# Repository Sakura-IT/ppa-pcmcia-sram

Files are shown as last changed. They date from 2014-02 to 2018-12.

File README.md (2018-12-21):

ppa-pcmcia-sram
===============

PCMCIA SRAM card created on ppa.pl forum.

* board - electrical schematics and board layout (Eagle, Gerber)
* cpld/src - CPLD core source (VHDL)
* docs - documentation (manual)

For history and rationale behind design decisions, See this thread: http://www.ppa.pl/forum/amiga/29264/budowa-kart-pamieci-sram-na-pcmcia

This board was sold and marketed as Sakura 4MB PCMCIA SRAM, primarily by Sakura IT, though several forks of this design exist.

Description
===========

Add 4MB of Fast RAM to your unexpanded Amiga 600/1200. This additional memory will make your system much faster and allow to run more demanding games and applications. It was designed by Jarosław Bieliński and Radosław Kujawa.

This memory expansion card has the following features:

* Adds 4MB of Fast RAM to Amiga 600 or Amiga 1200.
* Built using modern, high performance 55ns SRAM ICs (even faster than maximum Amiga 1200 slot access time).
* Accelerates unexpanded Amiga 1200 to at least 1.67 MIPS (according to SysInfo).
* Fully PCMCIA 2.1 compliant on an electrical level, smaller dimensions than normal PCMCIA card.
* Very simple installation - just insert the card into PCMCIA slot on the left side of Amiga.
* Compatible with all PCMCIA friendly accelerators and memory expansions.
* Open source design. 
* RoHS compliant, low power, environmentally friendly.
* Made by Amigans for Amigans!

We did our best to ensure that this card works on as many configurations as possible, but some accelerator and Fast RAM expansion designs are inherently incompatible with PCMCIA slot if more than 4MB of memory is installed. Note that PCMCIA SRAM should work with them anyway, if less than 4MB Fast was installed on the turbo card. Of course, if you don’t have any accelerator, you don’t have to worry about that.

The following A1200 cards are known to be PCMCIA compatible and should work correctly with any amount of memory installed:

* Blizzard 1230/1240/1260.
* Apollo 1240/1260.
* ACA 1220/1230/1231/1232.
* most other turbo cards supporting more than 8MB of Fast memory.
* 4MB Fast trapdoor expansions without CPU.

The following A1200 cards are known to be problematic if more than 4MB of memory is installed:

* Apollo/Elbox/Viper 1230LC.
* M-Tec 1230/28.
* Blizzard 1220 if more than 4MB RAM installed.
* 8MB Fast trapdoor expansions without CPU.

The following A600 cards are known to be PCMCIA compatible and should work correctly:

* ACA630.
* 4MB Fast expansions attached on top of processor.

The following A600 cards are known to be problematic if more than 4MB of memory is installed:

* ACA620 (in default PCMCIA-incompatible mode).
* Ninetails (in default PCMCIA-incompatible mode).
* 8MB/9.5MB Fast expansions attached on top of processor.

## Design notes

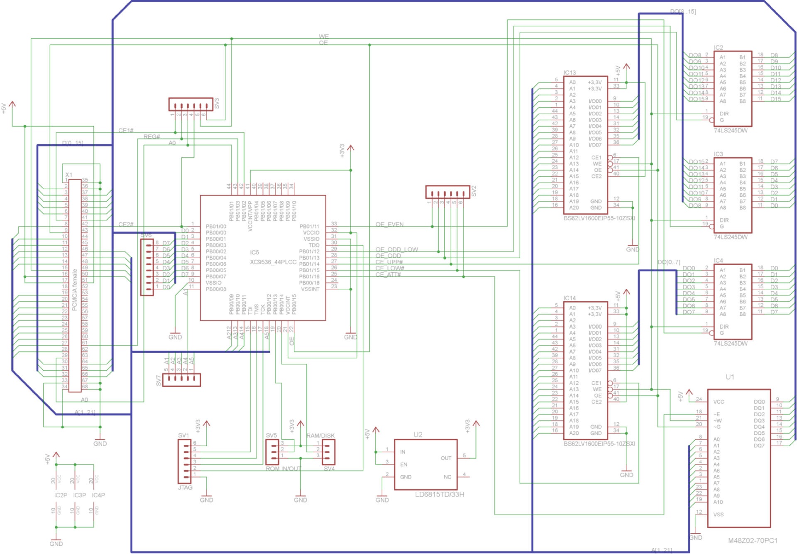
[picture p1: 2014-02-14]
board/Proto/schematics.jpg

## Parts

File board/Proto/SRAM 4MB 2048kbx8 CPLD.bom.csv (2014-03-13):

Part | Value | Device | Package | Description | MF | MPN | OC_FARNELL | OC_NEWARK | PACKAGE | SUPPLIER
C1 | 1uF/6,3V | CPOL-EUB | PANASONIC_B | POLARIZED CAPACITOR, European symbol
C2 | 1uF/6,3V | CPOL-EUB | PANASONIC_B | POLARIZED CAPACITOR, European symbol
C3 | 0,1uF | C-EUC0603 | C0603 | CAPACITOR, European symbol
C4 | 0,1uF | C-EUC0603 | C0603 | CAPACITOR, European symbol
C5 | 0,1uF | C-EUC0603 | C0603 | CAPACITOR, European symbol
C6 | 0,1uF | C-EUC0603 | C0603 | CAPACITOR, European symbol
C7 | 0,1uF | C-EUC0603 | C0603 | CAPACITOR, European symbol
C9 | 0,1uF | C-EUC0603 | C0603 | CAPACITOR, European symbol
C10 | 0,1uF | C-EUC0603 | C0603 | CAPACITOR, European symbol
C11 | 0,1uF | C-EUC0603 | C0603 | CAPACITOR, European symbol
C12 | 0,1uF | C-EUC0603 | C0603 | CAPACITOR, European symbol
C13 | 0,1uF | C-EUC0603 | C0603 | CAPACITOR, European symbol
IC1 | M48Z02-70PC1 | M48Z02-70PC1 | DIP254P1524X965-24 | 5 V, 16 Kbit (2 Kb x 8) ZEROPOWER® SRAM |  | M48Z02-70PC1 | 9755748 | 89K1473 | PDIP-24 | STMICROELECTRONICS
IC2 | 74LS245DW | 74LS245DW | SO20W | Octal BUS TRANSCEIVER, 3-state
IC3 | 74LS245DW | 74LS245DW | SO20W | Octal BUS TRANSCEIVER, 3-state
IC4 | 74LS245DW | 74LS245DW | SO20W | Octal BUS TRANSCEIVER, 3-state
IC5 | XC9536_44PLCC | XC9536_44PLCC | PLCC44 | xc9536_pc44 XC9500 In-System Programmable CPLD Family |  | XC9536-15PCG44C | 1193226 | 98K3376
IC6 | BS62LV1600EIP55-10ZSXI | BS62LV1600EIP55-10ZSXI | TSOPII-Z44 | Source: CYPRESS cy7c1059dv33_8.pdf
IC7 | BS62LV1600EIP55-10ZSXI | BS62LV1600EIP55-10ZSXI | TSOPII-Z44 | Source: CYPRESS cy7c1059dv33_8.pdf
IC8 | LD6815TD/33H | LD6815TD/33H | SOT95P275X110-5N | LDO, 5.5V, 0.25VDO, 0.15A, 3.3V, 5TSOP |  | LD6815TD/33H | 2308302 | 69W9575 | TSOP-5 | NXP
SV1 | JTAG | MA06-1 | MA06-1 | PIN HEADER |  |  | unknown | unknown
SV2 |  | MA06-1 | MA06-1 | PIN HEADER |  |  | unknown | unknown
SV3 |  | MA06-1 | MA06-1 | PIN HEADER |  |  | unknown | unknown
SV4 | RAM/DISK | MA03-1 | MA03-1 | PIN HEADER |  |  | unknown | unknown
SV5 | ROM IN/OUT | MA03-1 | MA03-1 | PIN HEADER |  |  | unknown | unknown
SV6 |  | MA08-1 | MA08-1 | PIN HEADER |  |  | unknown | unknown
SV7 |  | MA05-1 | MA05-1 | PIN HEADER |  |  | unknown | unknown
X1 | PCMCIA female | 9M681X03TB9M681Z04 | 9M681X04

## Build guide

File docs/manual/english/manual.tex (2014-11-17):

\documentclass[10pt,a4paper]{article}
\usepackage{graphicx}
\usepackage{hyperref}
\usepackage[utf8x]{inputenc}

\begin{document}

\begin{titlepage}
\begin{center}

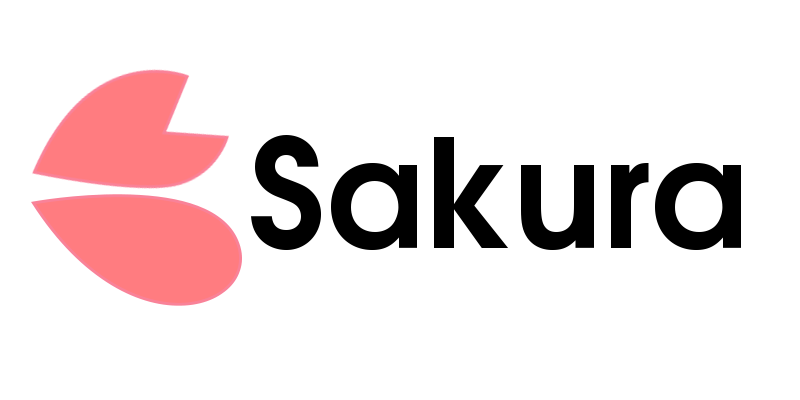
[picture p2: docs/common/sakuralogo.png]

\vfill

\huge
4MB PCMCIA SRAM

User's Manual

\vspace*{1cm}

\normalsize
Low cost Fast RAM expansion for Amiga 600/1200.

\vspace*{5cm}

\today

\end{center}
\end{titlepage}

\section*{Overview}

Thank you for purchasing Sakura 4MB PCMCIA SRAM expansion! This product has the following features:

\begin{itemize}
	\item Adds 4MB of Fast RAM to Amiga 600 or Amiga 1200.
	\item Accelerates unexpanded Amiga 1200 to at least 1.67 MIPS (according to SysInfo).
	\item Built using modern, high performance 55ns SRAM ICs.
	\item Very simple installation - just insert the card into PCMCIA slot on the left side of Amiga.
	\item Compatible with all PCMCIA friendly accelerators and memory expansions\footnote{We did our best to ensure that this card works on as many configurations as possible, but some accelerator and Fast RAM expansion designs are inherently incompatible with PCMCIA slot if more than 4MB of memory is installed. Note that PCMCIA SRAM should work with them anyway, if less than 4MB Fast was installed on the turbo card. Of course, if you don’t have any accelerator, you don’t have to worry about that.}.
	\item Open source design\footnote{Visit the source code reposity: \url{https://github.com/rkujawa/ppa-pcmcia-sram} .} under CC-BY-SA (board) and MIT (CPLD core) licenses.
	\item Made by Amigans for Amigans! 
\end{itemize}

\section*{Installation}

The installation process is very easy. To install the expansion perform the following steps:

\begin{itemize}
	\item Power down your Amiga.
	\item Slide the expansion card into PCMCIA slot, located on the left side of your computer. The card's components should be facing upwards.
	\item Be sure the {\tt RAM/disk} switch is in {\tt RAM} position.
	\item Turn on your Amiga and enjoy additional 4MB of memory.
\end{itemize}

Your Amiga should start as normal, albeit a bit faster. After installation you can confirm that the board is working correctly, by checking amount of available memory on the Workbench top menu bar, or with the {\tt avail} or {\tt ShowConfig} commands. Popular SysInfo tool will report the additional 4MB of memory under {\tt card.resource} name.

\section*{Technical details}

\begin{center}

\end{center}

Revision 2.x Sakura boards are built around Alliance Memory AS6C3216, which is a 55ns 32 megabit SRAM chip with 16-bit data bus. The memory is accessible within high 4MB of Zorro 2 memory ({\tt 0x600000-0x9FFFFF}) range.

Control signals for SRAM are generated by Xilinx XC9536XL CPLD, based on PCMCIA slot access signals.

This expansion is a completely autoconfiguring device. Memory is automatically added to the system memory pool by Kickstart. Autoconfiguration process is done according to the Card Information Structure (CIS) provided by the card, which is parsed by {\tt card.resource}. Naturally, this process only takes place during system startup, so inserting card into Amiga when it is running does not cause memory to be added. If necessary it could be added manually with {\tt AddMem} command (avaialble on aminet), although this is not required during normal operation.

Sakura expansion CIS contains optimal settings that allow best possible PCMCIA slot peformance:
\begin{itemize}
	\item On Amiga 600 Gayle chip is configured for 570ns access time by default, which results in performance similar to Fast RAM expansions attached on top of 68000 CPU.
	\item On Amiga 1200 the default configuration is 250ns access time, but Kickstart automatically reconfigures Gayle for 100ns access, according to CIS. This results in some performance increase compared to an unexpanded Amiga 1200. Contrary to popular opinions, Amiga 1200 equipped with high performance, correctly configured PCMCIA SRAM expansion (like this one) is performing better than Chip RAM only system.
\end{itemize}

CIS ROM is also implemented within XC9536XL CPLD.

Sakura expansion is electrically compatible with PCMCIA 2.1 standard, however physical dimensions of the card are smaller. While in theory this card should work with other devices, using it with computers other than Amiga 600/1200 was never tested and is discouraged.

\section*{Temporary disk mode}

It is possible to use the Sakura board as temporary virtual disk. To switch the board into this mode, take the following steps:
\begin{itemize}
	\item Turn off your Amiga and remove the Sakura board.
	\item Set the {\tt RAM/disk} switch into {\tt disk} position.
	\item Turn on your Amiga, instert the Sakura after booting into Workbench.
	\item Run the {\tt PrepCard} application.
	\item Select {\tt Prepare as disk} option.
	\item After your card is successfully prepared, reboot the Amiga.
	\item Notice the new volume named {\tt Empty} on your Workbench screen. Enjoy your temporary 4MB storage.

Card in this mode is handled by the device {\tt CC0}, which is provided by the Kickstart.
\end{itemize}

\section*{Troubleshooting}

\begin{itemize}
	\item Q: After powering up the Amiga, the memory does not appear on the Workbench bar and the output of {\tt ShowConfig} command.
	\item A: Check if the card is properly inserted into PCMCIA slot. Check if the {\tt RAM/Disk} switch is in the {\tt RAM} position. Reboot the Amiga.
\end{itemize}

\begin{itemize}
	\item Q: The memory is not automatically added to the system if Sakura card is inserted when Amiga is already powered on. 
	\item A: The probe procedure for PCMCIA memory is executed only during system startup. Reboot the Amiga to see the additional memory. 
\end{itemize}

\begin{itemize}
	\item Q: {\tt PrepCard} utility refuses to start, stating that memory is already configured. 
	\item A: It is not necessary to use {\tt PrepCard} with Sakura board configured as RAM. Predefined CIS settings are selected with {\tt RAM/Disk} switch. It is possible to view the current CIS settings by starting the {\tt PrepCard} just after inserting the card into Amiga (i.e. before reboot). 
\end{itemize}

\begin{itemize}
	\item Q: Performance of my Amiga 1200 dropped after installing the card.
	\item A: Be sure that {\tt RAM/disk} switch is in {\tt RAM} position. If not then turn off your Amiga completely, wait a few seconds and set the switch in {\tt RAM} position. After power-on you should notice considerable speedup.
\end{itemize}

\section*{Acknowledgements}

Sakura expansion was designed by Radosław ,,strim'' Kujawa and Jarosław ,,jarob'' Bieliński. The original idea was suggested on PPA.pl forum by RomanWorkshop. 

All schematics and board layout files are licensed under Creative Commons Attribution-ShareAlike 4.0 license. CPLD core source is licensed under MIT license.

The card is made in Poland and conforms to RoHS standard. 

All new cards sold through our exclusive dealer, RetroAmi, are covered by 24 months warranty. Due to open source nature of the project, note that {\bf only} cards produced by us (and therefore sold through RetroAmi) are covered by this warranty. In case of necessary service repairs please contact the shop directly. Do not attempt to repair the card yourself, it will void the warranty. Do not remove the sticker on the back of the card - it contains serial number. Please save the invoice/bill as a proof of transaction.

Thanks to everyone who preordered the board - you made this project happen!

\section*{Contact}

In case of any questions/inquires please contact RetroAmi:

\url{http://retroami.com.pl/} 

\end{document}

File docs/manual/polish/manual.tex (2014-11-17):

\documentclass[10pt,a4paper]{article}
\usepackage{graphicx}
\usepackage{hyperref}
\usepackage[utf8x]{inputenc}
\usepackage{polski}

\begin{document}

\begin{titlepage}
\begin{center}


\vfill

\huge
4MB PCMCIA SRAM

Instrukcja Obsługi

\vspace*{1cm}

\normalsize
Tanie rozszerzenie Fast RAM dla Amigi 600/1200.

\vspace*{5cm}

\today

\end{center}
\end{titlepage}

\section*{Opis}

Dziękujemy za zakup rozszerzenia Sakura 4MB PCMCIA SRAM! Ten produkt ma następujące właściwości:

\begin{itemize}
	\item Rozszerza Amigę 600 lub 1200 o 4MB pamięci Fast RAM.
	\item Przyśpiesza nierozszerzoną Amigę 1200 do przynajmniej 1.67 MIPS (według SysInfo).
	\item Jest zbudowany z użyciem nowoczesnych, szybkich układów SRAM o czasie dostępu 55ns.
	\item Bardzo prosta instalacja - zwyczajnie włóż kartę w slot PCMCIA po lewej stronie Amigi.
	\item Kompatybilny z wszystkimi akceleratorami oraz rozszerzeniami pamięci przyjaznymi dla slotu PCMCIA\footnote{Zrobiliśmy wiele aby zapewnić działanie karty w największej możliwej ilości konfiguracji, ale niektóre akceleratory oraz rozszerzenia Fast RAM są z założenia niekompatybilne ze slotem PCMCIA jeśli zainstalowane jest więcej niż 4MB pamięci. Karta PCMCIA SRAM powinna działać z nimi tak czy inaczej, jeśli na owym rozszerzeniu zainstalowane jest 4MB pamięci lub mniej. Oczywiście, jeśli nie masz żadnego akceleratora ani rozszerzenia pamięci, to nie musisz się tym przejmować.}.
	\item Otwarty projekt\footnote{Odwiedź repozytorium kodu źródłowego: \url{https://github.com/rkujawa/ppa-pcmcia-sram} .} na licencji CC-BY-SA (płytka) oraz MIT (wsad CPLD).
	\item Stworzony przez Amigowców dla Amigowców! 
\end{itemize}

%To reduce the price, card is delivered without any kind of case. The case might be available in the future from 3rd party vendor.

\section*{Instalacja}

Procedura instalacji jest bardzo prosta. Aby zainstalować rozszerzenie wykonaj następujące kroki:

\begin{itemize}
	\item Wyłącz swoją Amigę.
	\item Wsuń kartę do slotu PCMCIA, zlokalizowanego po lewej stronie Twojego komputera. 
	%The card's components should be facing upwards.
	\item Upewnij się że przełącznik {\tt RAM/disk} jest ustawiony w pozycji {\tt RAM}.
	\item Włącz swoją Amigę i rozkoszuj się dodatkowymi 4MB pamięci.
\end{itemize}

Twoja Amiga powinna uruchomić się jak zazwyczaj, jednak nieco szybciej. Po instalacji możesz potwierdzić, że rozszerzenie działa prawidłowo, poprzez sprawdzenie ilości dostępnej pamięci na górnej belce Workbench'a, albo używając komendy {\tt avail} lub {\tt ShowConfig}. Popularne narzędzie SysInfo zaraportuje dodatkowe 4MB pamięci pod nazwą {\tt card.resource}.

\section*{Szczegóły techniczne}

\begin{center}

\end{center}

Karty Sakura w rewizji 2.x są zbudowane w oparciu o układ Alliance Memory AS6C3216, który jest 32-megabitowym układem SRAM z 16-bitową szyną danych, o czasie dostępu 55ns. Pamięć jest dostępna w górnych 4MB przestrzeni Zorro 2 ({\tt 0x600000-0x9FFFFF}).

Sygnały kontrolne dla układu SRAM są generowane przez CPLD Xilinx XC9536XL, bazując na sygnałach dostępu do slotu PCMCIA.

To rozszerzenie jest konfigurowane w pełni automatycznie. Pamięć jest dodawana do systemowej puli pamięci przez Kickstart. Proces automatycznej konfiguracji jest wykonywany zgodnie z danymi przedstawianymi przez kartę w strukturze CIS (ang. Card Information Structure), które jest analizowana przez {\tt card.resource}. Naturalnie, ten proces ma miejsce jedynie podczas startu systemu, więc włożenie karty do Amigi podczas jej pracy nie powoduje automatycznego dodania pamięci. Jeśli jest to konieczne, istnieje możliwość ręcznego dodania pamięci za pomocą komendy {\tt AddMem} (dostępnej na aminecie), jednakże to nie jest wymagane podczas normalnej pracy. 

CIS rozszerzenia Sakura zawiera optymalne ustawienia, ktore pozwalają na uzyskanie optymalnej wydajności slotu PCMCIA:
\begin{itemize}
	\item W przypadku Amigi 600 układ Gayle jest konfigurowany domyślnie do pracy z czasem dostępu 570ns, co pozwala na osiągnięci wydajności podobnej do rozszerzeń Fast RAM zakładanych na procesor 68000.
	\item W przypadku Amigi 1200 domyślną konfiguracją jest czas dostępu 250ns, ale Kickstart automatycznie rekonfiguruje Gayle na dostęp z czasem 100ns, zgodnie z informacją w CIS. To skutkuje pewnym zwiększeniem wydajności w porównaniu do nierozszerzonej Amigi 1200. Przeciwnie do popularnych opinii, Amiga 1200 wyposażona w wydajne, poprawnie skonfigurowane rozszerzenie PCMCIA SRAM (takie jak Sakura) będzie oferowała wydajność większą niż system wyposażony jedynie w Chip RAM.
\end{itemize}

ROM zawierający CIS jest także zaimplementowany w CPLD XC9536XL.

Rozszerzenie Sakura jest elektrycznie kompatybilne ze standardem PCMCIA 2.1, jednakże fizyczne wymiary karty są mniejsze. W teorii to rozszerzenie powinno działać z innymi urządzeniami, jednak użycie z innymi komputerami niż Amiga 600/1200 nigdy nie zostało przetestowane i z tego względu nie jest zalecane.

\section*{Tryb tymczasowego dysku}

Jest możliwe wykorzystanie karty Sakura jako tymczasowego dysku. Aby przełączyć kartę w ten tryb, wykonaj następujące czynności:
\begin{itemize}
	\item Wyłącz swoją Amigę i wyjmij kartę Sakura.
	\item Ustaw przełącznik {\tt RAM/disk} w pozycji {\tt disk}.
	\item Włącz swoją Amigę, włóż kartę Sakura po uruchomieniu do Workbencha.
	\item Uruchom program {\tt PrepCard}.
	\item Skorzystaj z opcji {\tt Prepare as disk}.
	\item Gdy karta zostanie przygotowana, zrestartuj Amigę.
	\item Zauważ nowy wolumin {\tt Empty} na blacie Workbencha. Rozkoszuj się tymczasowym dyskiem 4MB.

Karta w tym trybie jest obsługiwana przez urządzenie {\tt CC0}, które dostarczone jest przez Kickstart.
\end{itemize}

\section*{Rozwiązywanie problemów}

\begin{itemize}
	\item P: Po włączeniu Amigi, pamięć nie pojawia się na belce Workbencha ani w wyniku polecenia {\tt ShowConfig}.
	\item O: Sprawdź czy karta jest prawidłowo umieszczona w slocie. Sprawdź czy przełącznik {\tt RAM/Disk} znajduje się w pozycji {\tt RAM}. Zrestartuj Amigę.
\end{itemize}

\begin{itemize}
	\item P: Pamięć nie jest automatycznie dodana do systemu w momencie włożenia karty, gdy Amiga jest już włączona.
	\item O: Procedura sprawdzająca czy pamięć PCMCIA jest obecna, wykonywana jest jedynie podczas startu systemu. Zrestartuj Amigę aby zobaczyć dodatkową pamięć. 
\end{itemize}

\begin{itemize}
	\item P: Program {\tt PrepCard} odmawia uruchomoenia, twierdząc że pamięć jest już skonfigurowana.
	\item O: Nie ma potrzeby używania programu {\tt PrepCard} z kartą Sakura skonfigurowaną jako RAM. Predefiniowane ustawienia CIS są wybierane przełącznikiem {\tt RAM/Disk}. Jest możliwe obejrzenie tych ustawień poprzez uruchomienie {\tt PrepCard} bezpośrednio po włożeniu karty do slotu (przed restartem). 
\end{itemize}

\begin{itemize}
	\item P: Wydajność mojej Amigi 1200 spadła po zainstalowaniu karty.
	\item O: Upewnij się, że przełącznik {\tt RAM/disk} znajduje się w pozycji {\tt RAM}. Jeśli nie to wyłącz całkowicie Amige, poczekaj kilka sekund, ustaw przełącznik w pozycji {\tt RAM}. Po uruchomieniu zauważysz znaczne przyśpieszenie.
\end{itemize}

\section*{Zastrzeżenia i podziękowania}

Rozszerzenie Sakura zostało opracowane przez Radosława ,,strim'' Kujawa oraz Jarosława ,,jarob'' Bielińskiego. Oryginalny pomysł został podsunięty na forum PPA.pl przez użytkownika RomanWorkshop. 

Wszystkie schematy i układ płytki są dostępne na licencji Creative Commons Attribution-ShareAlike 4.0. Wsad do układu CPLD został udostępniony na licencji MIT.

Karta została wyprodukowana w Polsce i jest zgodna ze standardem RoHS. 

Wszystkie nowe karty sprzedawane przez naszego wyłącznego sprzedawcę -- RetroAmi -- są objęte 24 miesięczną  gwarancją. Z uwagi na otwartą naturę tego projektu, zwróć uwagę że {\bf tylko} karty wyprodukowane przez nas (a więc sprzedawane przez RetroAmi) są objęte tą gwarancją. W przypadku wymaganych napraw gwarancyjnych prosimy o kontaktowanie się bezpośrednio ze sprzedawcą. Nie próbuj naprawiać karty samemu, spowoduje to utratę gwrancji. Nie usuwaj naklejki z karty - zawiera ona numer seryjny. Proszę zachować rachunek/fakturę jako dowód zakupu.

Dziękujemy wszystkim, którzy zamówili tą kartę - to wy sprawiliście, że ten projekt się udał!

\section*{Kontakt}

W przypadku jakichkolwiek pytań prosimy o kontakt z RetroAmi:

\url{http://retroami.com.pl/} 

\end{document}

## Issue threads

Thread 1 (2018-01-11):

Non-attribute memory SRAM cards

toastedcrumpets, 2018-01-11:
Hi!
Thanks for this amazing project. I'm currently looking for SRAM cards for old test equipment (in particular LeCroy 9300 series scopes). They require non-attribute memory PCMCIA SRAM cards, do you have any advice on how the CPLD VHDL might need to be modified to remove the CIS/attribute memory?
Kind regards,
Marcus

rkujawa, 2018-01-11:
Hi.

That should be relatively straightforward. Minimal modification removing attribute memory, would require changing `ce_attr_internal` to always be in an inactive state (1, since it's active low).

I.e. change lines 107-109 of main.vhd to:
```
ce_attr_internal <= '1';
```

This will essentially disable decoding of attribute ROM.

toastedcrumpets, 2018-01-11:
Thanks that's really simple. Do you still sell these via http://retroami.com.pl/? There's a number of people who might be interested in buying them over at the LeCroy users group if they work, but I'd like to test one first if I can.

rkujawa, 2018-01-12:
The cards are out of stock and for the time being, I am not planning a new production run (due to personal issues). So most likely you will need to make your own card. I am aware of quite a few people who have already done homebrew production of these cards.

Please note that the cards were not tested in anything but Amiga computers. They are also physically shorter than normal PCMCIA cards, so depending on the slot in your LeCroy scope, it might be necessary to adjust the PCB design. Also see issue #2.

toastedcrumpets, 2018-01-12:
Ah no problem, I hope your personal issues are swiftly resolved and thank you again for putting this together. I've seen that the Xilinx part for the v2.1 are out of production, but the v2.2 uses a BGA part which I've never soldered before, so I might try a 2mb card from ebay first before I try building my own!

rkujawa, 2018-01-13:
@toastedcrumpets You can use XC9536XL-10VQG44C in v2.1, this is still in production.

toastedcrumpets, 2018-01-19:
Thanks, I've ordered an SRAM from Ebay for now, but I don't doubt we might start making these if more scopes come in!

Kobbe1, 2024-05-05:
@toastedcrumpets sorry for resurrecting this but I am looking for an PCMCIA card for an old LeCroy scope too as it seems to have lost it's firmware, bit difficult to get my hands on one these days, so was wondering if you ever got this PCB built?

toastedcrumpets, 2024-05-05:
Hey, sorry no I didn't try it as I only needed the one card. If there's demand and no alternative source I could do a manufacturing run of these if needed with the vhdl changed, but I'm not planning this myself at the current time

Closed 2018-01-12.

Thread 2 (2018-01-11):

Board version 2.2 does not work reliably with ISSI PSRAM.

rkujawa, 2018-01-11:
Numerous tests have shown that ISSI PSRAM (as specified in board revision 2.2 BOM) does not work reliably. If one wants to build a card based on 2.2 PCB, then AS6C3216-55BIN should be used.

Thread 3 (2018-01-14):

PCMCIA connector EOL

rhaamo, 2018-01-14:
Hi,

On 2.2 PCB, I see that the PCMCIA connector is an ```FCI-10014744-002SLF```  and is out of stock/obsolete in Farnell and Mouser and pretty much everywhere, do you known a replacement for it ?

rkujawa, 2018-01-14:
Unfortunately, I am not aware of any direct replacement (I wasn't even aware that it is EOL now).

rhaamo, 2018-01-14:
Looks like Digikey still have PCMCIA connectors in stock.

It looks like http://www.plccenter.co.uk/Buy/ARROW/10014744002SLF?redirect=true may have this connector from ARROW and FIRING CIRCUITS. If it's the same one it could do the job unless the limited stock runs out.

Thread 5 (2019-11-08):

Question: Possible to add PCB layout and list of up-to-date components for self build?

lovrenco, 2019-11-08:
Hello,
Is it possible to add PCB layout and list of components which can be bought for self build purpose?
Or, is it possible tu purchase kit from you?

It would be great. Thanks,

rkujawa, 2019-11-08:
PCB layout is available in the repo, both in source form (Eagle brd files) and Gerber files. List of components can be exported from the project.

However, note that components used here are out of production.

Mr. @jensma has updated the project, modified it for easier DIY assembly, and ported to KiCad: https://github.com/jensma/ppa-pcmcia-sram .

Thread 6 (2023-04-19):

Code Execution Error in XP

harishbangalore, 2023-04-19:
Hi,
We are having issues during code exection using SRAM, please find the attached screenshots, can somebody help in this regard.

Regards,

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

rkujawa, 2023-04-19:
Hello.

It is very difficult to say what may be wrong based on just the screen shots you have provided.

I have no idea what your program does and whether it is correct, when it comes to operation under Windows. Note that XP has memory protection and you can't just use pointer dereference to access physical memory range, you need to use some driver abstraction to access the card. How it's done on Windows, I have no idea, I have never programmed under Windows. The displayed error is very generic and may mean anything.

Also, this card was never tested in a PC computer, so I have no idea if there's any problem with the design that would prevent it from working on Windows.

Which revision did you use? Only revision 2.1 was production-grade.

I would also suggest to check for any manufacturing problems (bad connection, faulty ICs, solder joints etc.).

rkujawa, 2023-04-19:
Btw. if you're using the program from `test` directory in source tree, it will not work under Windows. It's not a hardware problem - the program would have to be rewritten for Windows.

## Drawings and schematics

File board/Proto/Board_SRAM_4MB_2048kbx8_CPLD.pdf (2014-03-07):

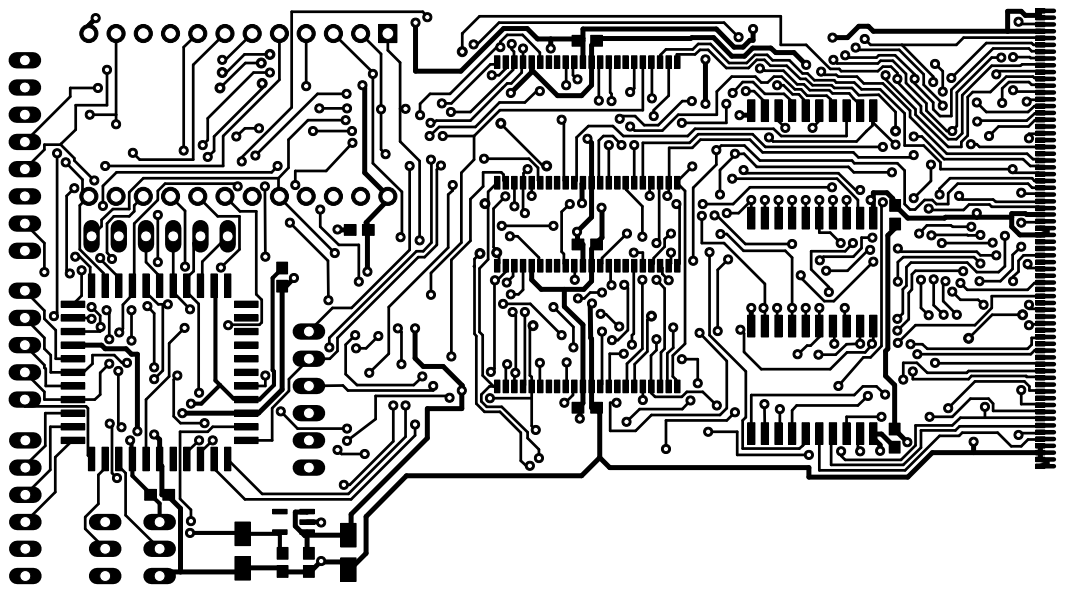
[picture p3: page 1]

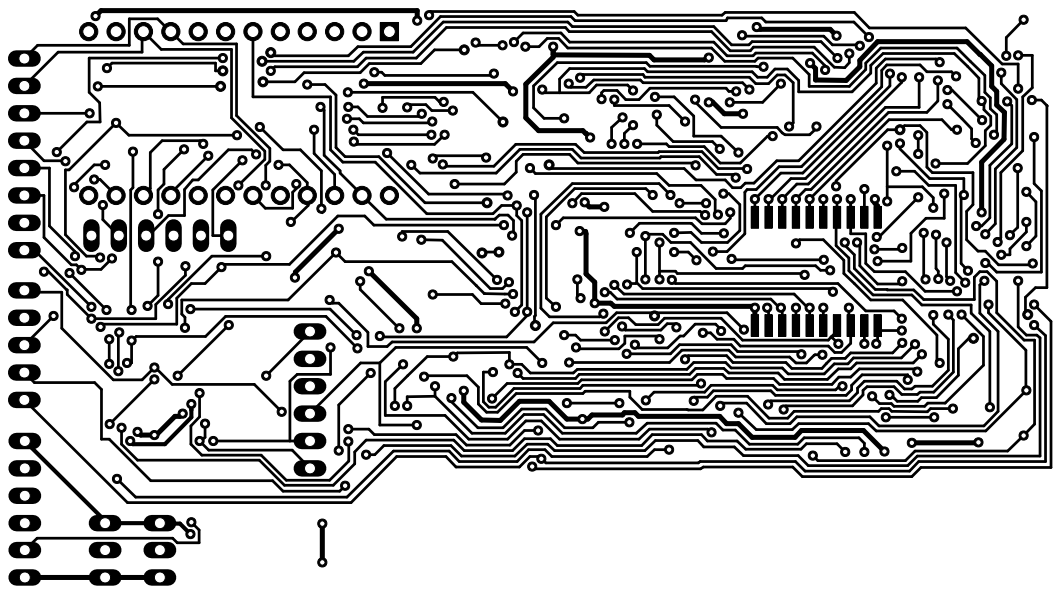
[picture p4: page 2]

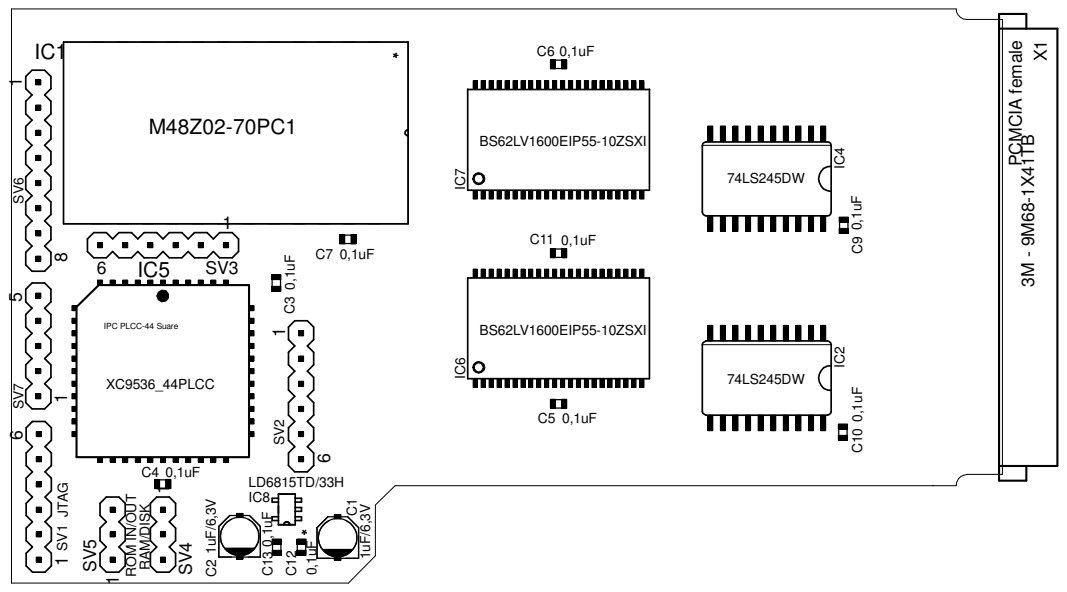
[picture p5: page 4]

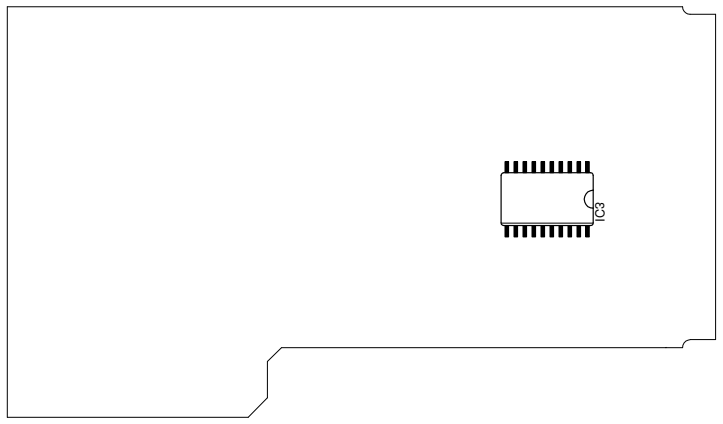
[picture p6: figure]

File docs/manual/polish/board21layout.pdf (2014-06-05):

IC1

### AS6C3216-55

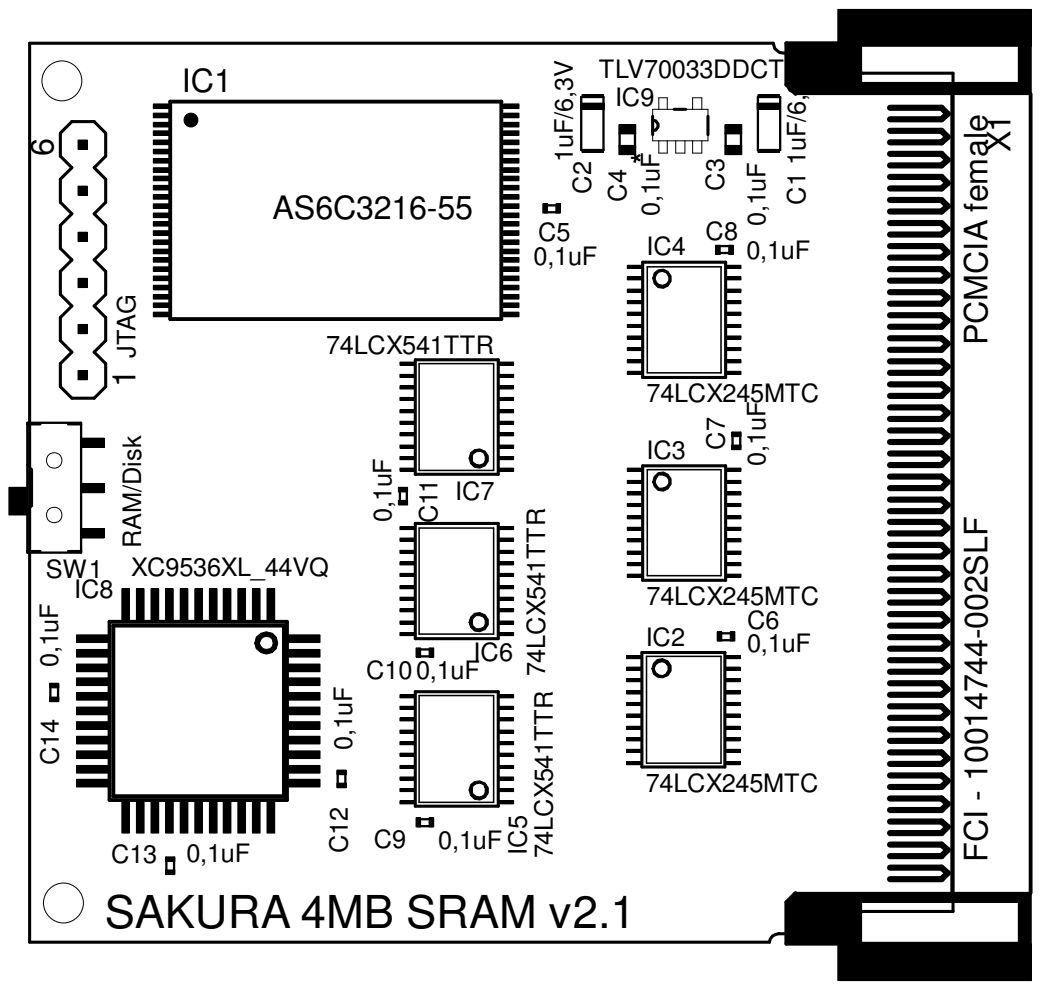
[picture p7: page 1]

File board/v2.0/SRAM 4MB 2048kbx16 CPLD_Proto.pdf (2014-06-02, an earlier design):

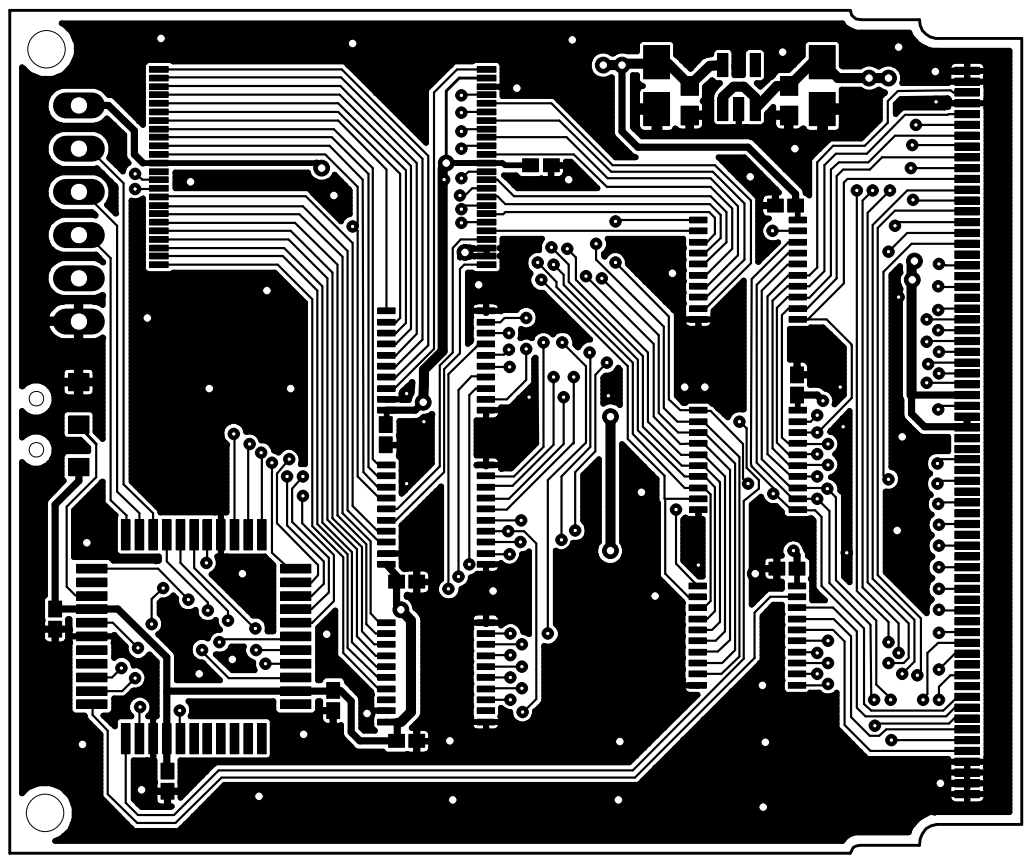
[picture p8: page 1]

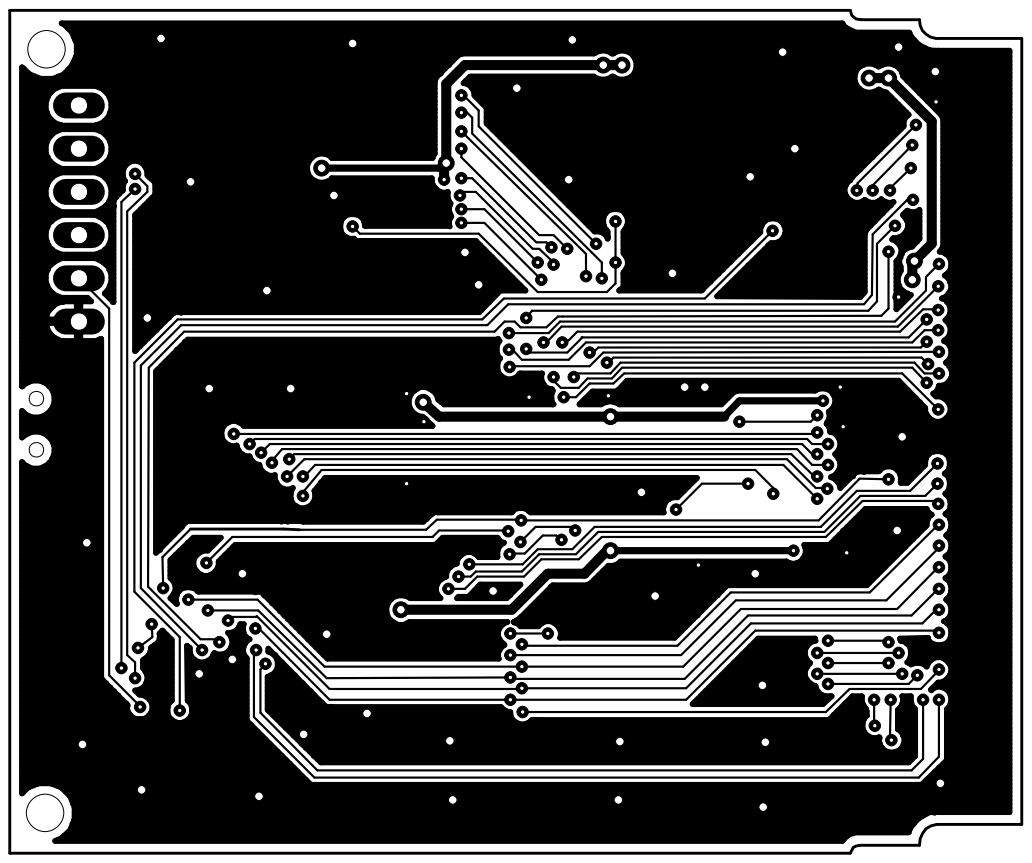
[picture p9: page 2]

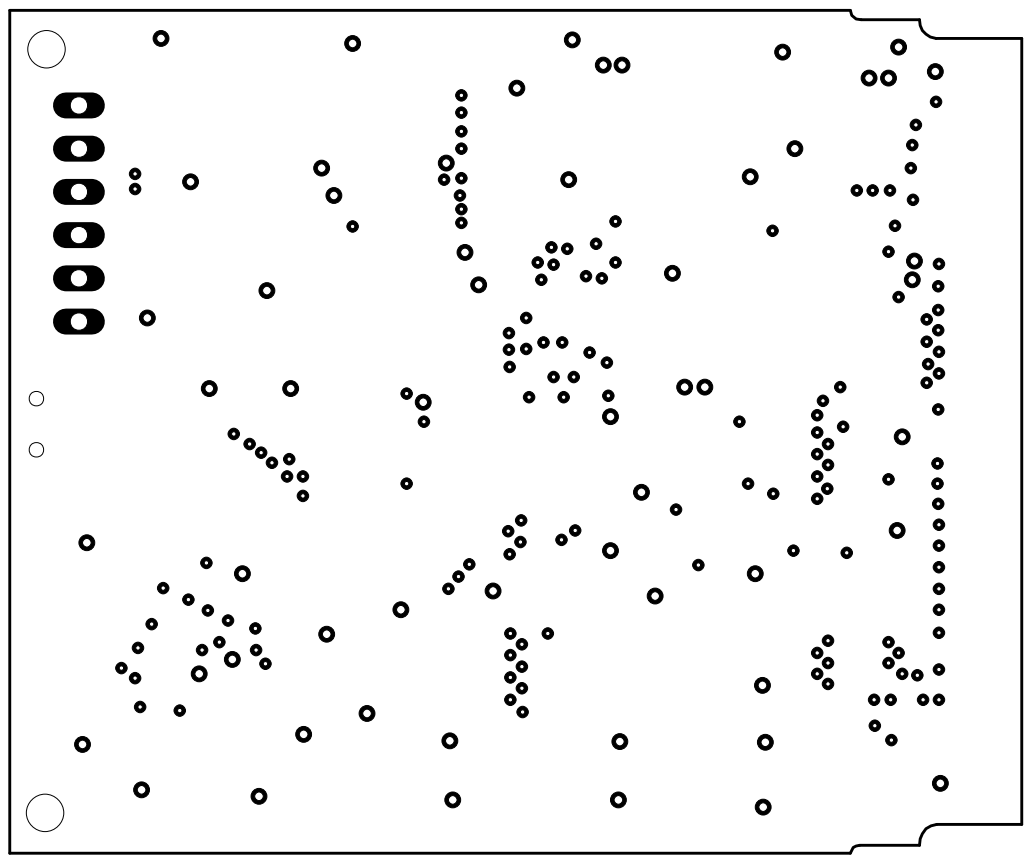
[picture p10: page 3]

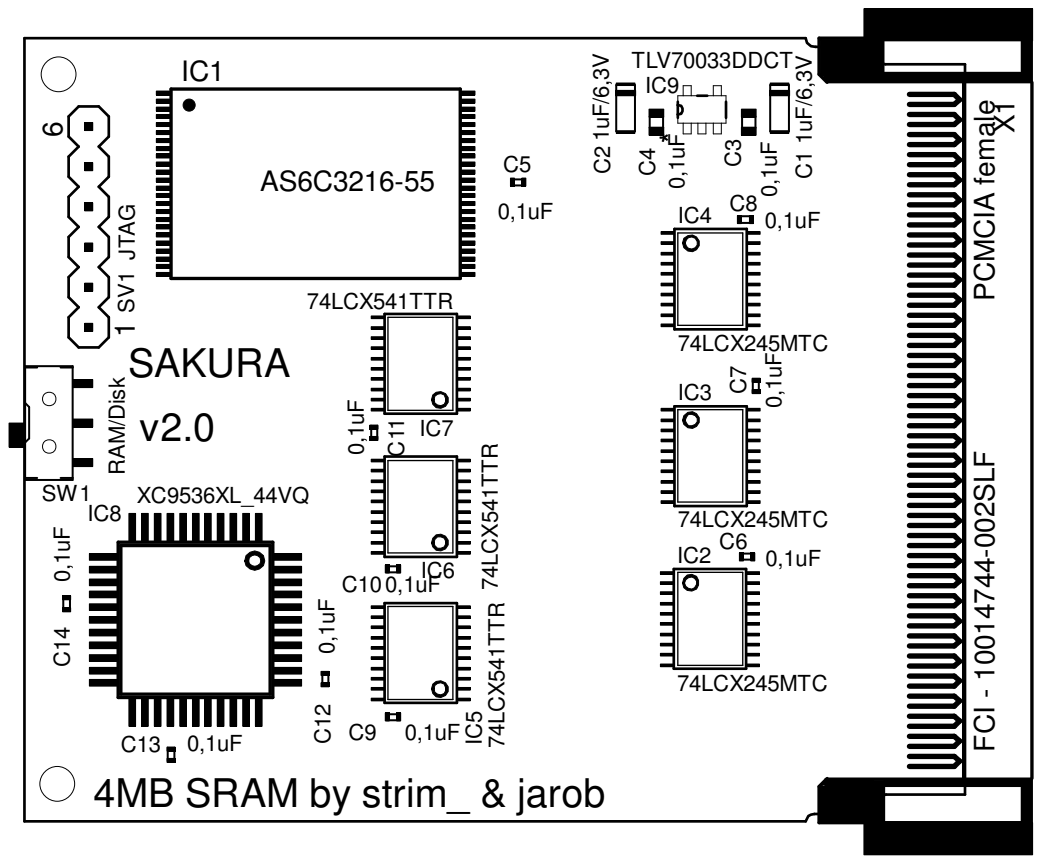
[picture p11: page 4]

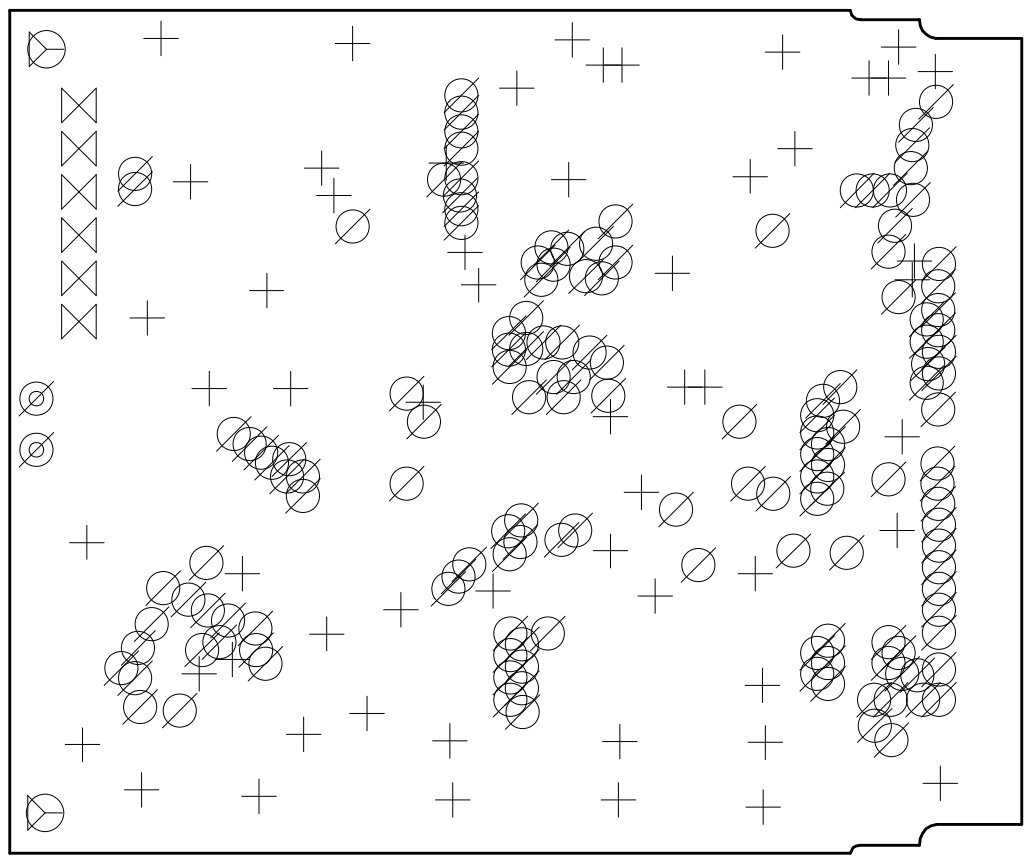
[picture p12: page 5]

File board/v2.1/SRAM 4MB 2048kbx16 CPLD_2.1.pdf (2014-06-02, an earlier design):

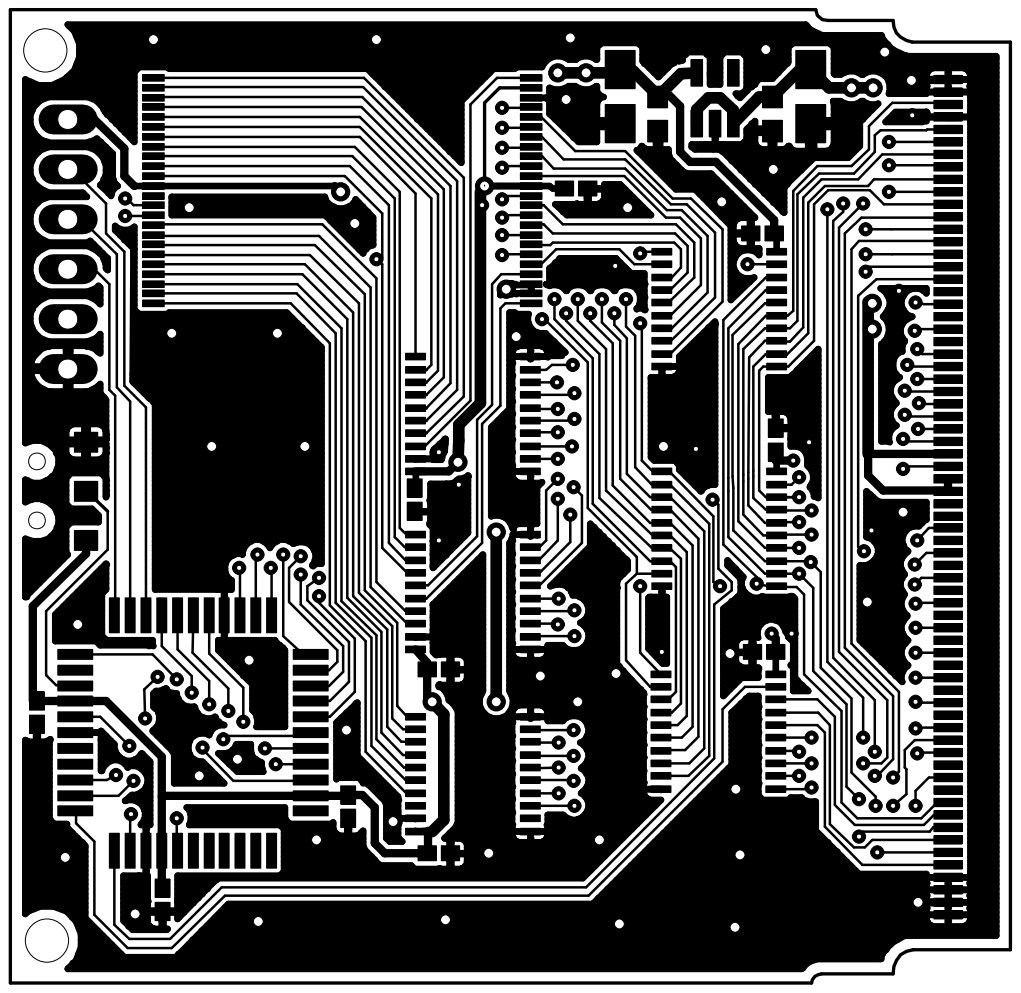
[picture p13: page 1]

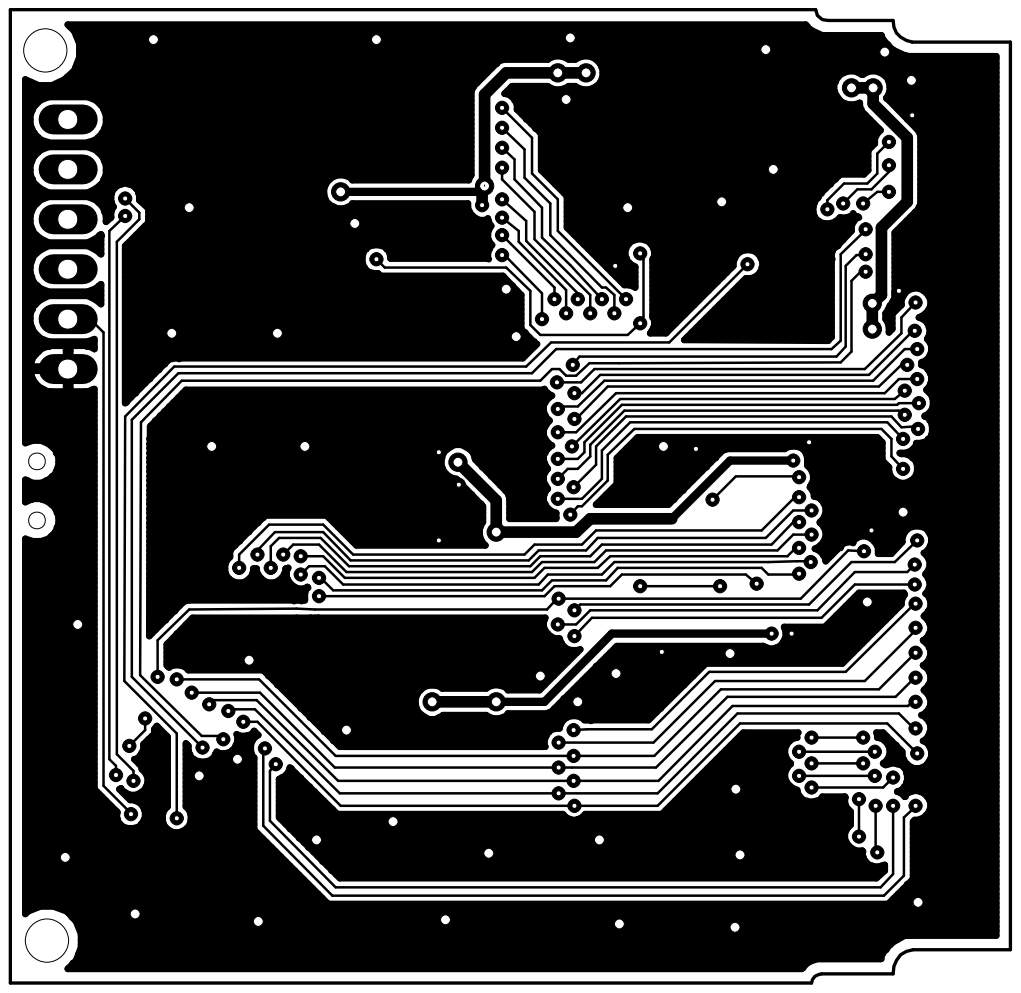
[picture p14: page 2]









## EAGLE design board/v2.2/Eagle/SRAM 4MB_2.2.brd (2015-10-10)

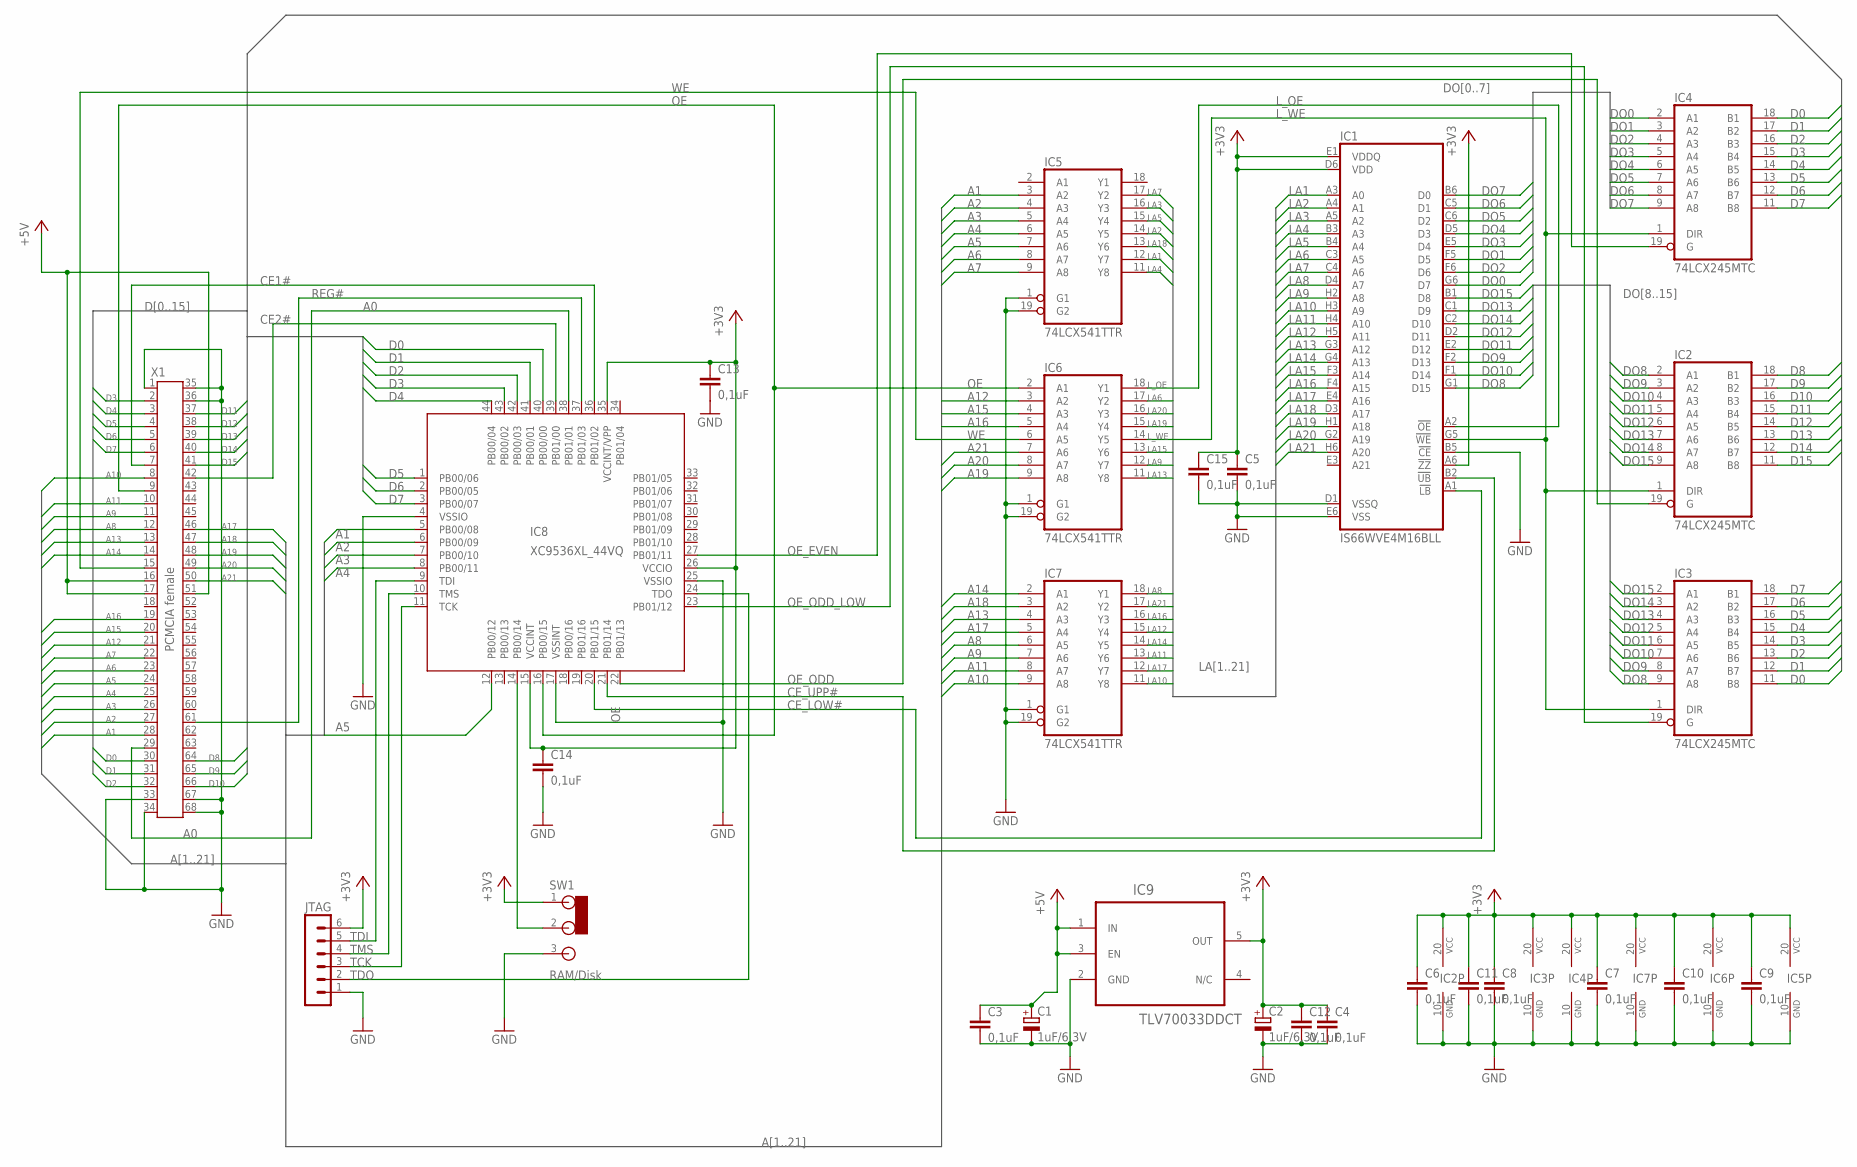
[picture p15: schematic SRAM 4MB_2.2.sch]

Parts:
C1, C2: 1uF/6,3V; A/3216-18R
C3, C4: 0,1uF; C0603
C5, C6, C7, C8, C9, C10, C11, C12, C13, C14, C15: 0,1uF; C0402K
IC1: IS66WVE4M16BLL; TFBGA48
IC2, IC3, IC4: 74LCX245MTC; TSSOP20
IC5, IC6, IC7: 74LCX541TTR; TSSOP20
IC8: XC9536XL_44VQ; SQFP-S-10X10-44
IC9: TLV70033DDCT; SOT95P280X110-5N
JTAG: MA06-1
SW1: RAM/Disk; SWITCH2
X1: PCMCIA female; 9M681X04

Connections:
+3V3: C2.+, C4.1, C5.1, C6.1, C7.1, C8.1, C9.1, C10.1, C11.1, C12.1, C13.1, C14.1, C15.1, IC1.A6 (!ZZ), IC1.D6 (VDD), IC1.E1 (VDDQ), IC2.20 (VCC), IC3.20 (VCC), IC4.20 (VCC), IC5.20 (VCC), IC6.20 (VCC), IC7.20 (VCC), IC8.15 (VCCINT), IC8.26 (VCCIO), IC8.35 (VCCINT/VPP), IC9.5 (OUT), JTAG.6, SW1.1
+5V: C1.+, C3.1, IC9.1 (IN), IC9.3 (EN), X1.16, X1.17, X1.51
A0: IC8.38 (PB01/01), X1.29
A1: IC5.3 (A2), IC8.5 (PB00/08), X1.28
A2: IC5.4 (A3), IC8.6 (PB00/09), X1.27
A3: IC5.5 (A4), IC8.7 (PB00/10), X1.26
A4: IC5.6 (A5), IC8.8 (PB00/11), X1.25
A5: IC5.7 (A6), IC8.12 (PB00/12), X1.24
A6: IC5.8 (A7), X1.23
A7: IC5.9 (A8), X1.22
A8: IC7.6 (A5), X1.12
A9: IC7.7 (A6), X1.11
A10: IC7.9 (A8), X1.8
A11: IC7.8 (A7), X1.10
A12: IC6.3 (A2), X1.21
A13: IC7.4 (A3), X1.13
A14: IC7.2 (A1), X1.14
A15: IC6.4 (A3), X1.20
A16: IC6.5 (A4), X1.19
A17: IC7.5 (A4), X1.46
A18: IC7.3 (A2), X1.47
A19: IC6.9 (A8), X1.48
A20: IC6.8 (A7), X1.49
A21: IC6.7 (A6), X1.50
CE1#: IC8.36 (PB01/02), X1.7
CE2#: IC8.39 (PB01/00), X1.42
CE_LOW#: IC1.A1 (!LB), IC8.20 (PB01/15)
CE_UPP#: IC1.B2 (!UB), IC8.21 (PB01/14)
D0: IC3.11 (B8), IC4.18 (B1), IC8.40 (PB00/00), X1.30
D1: IC3.12 (B7), IC4.17 (B2), IC8.41 (PB00/01), X1.31
D2: IC3.13 (B6), IC4.16 (B3), IC8.42 (PB00/03), X1.32
D3: IC3.14 (B5), IC4.15 (B4), IC8.43 (PB00/02), X1.2
D4: IC3.15 (B4), IC4.14 (B5), IC8.44 (PB00/04), X1.3
D5: IC3.16 (B3), IC4.13 (B6), IC8.1 (PB00/06), X1.4
D6: IC3.17 (B2), IC4.12 (B7), IC8.2 (PB00/05), X1.5
D7: IC3.18 (B1), IC4.11 (B8), IC8.3 (PB00/07), X1.6
D8: IC2.18 (B1), X1.64
D9: IC2.17 (B2), X1.65
D10: IC2.16 (B3), X1.66
D11: IC2.15 (B4), X1.37
D12: IC2.14 (B5), X1.38
D13: IC2.13 (B6), X1.39
D14: IC2.12 (B7), X1.40
D15: IC2.11 (B8), X1.41
DO0: IC1.G6 (D7), IC4.2 (A1)
DO1: IC1.F5 (D5), IC4.3 (A2)
DO2: IC1.F6 (D6), IC4.4 (A3)
DO3: IC1.E5 (D4), IC4.5 (A4)
DO4: IC1.D5 (D3), IC4.6 (A5)
DO5: IC1.C6 (D2), IC4.7 (A6)
DO6: IC1.C5 (D1), IC4.8 (A7)
DO7: IC1.B6 (D0), IC4.9 (A8)
DO8: IC1.G1 (D15), IC2.2 (A1), IC3.9 (A8)
DO9: IC1.F2 (D13), IC2.3 (A2), IC3.8 (A7)
DO10: IC1.F1 (D14), IC2.4 (A3), IC3.7 (A6)
DO11: IC1.E2 (D12), IC2.5 (A4), IC3.6 (A5)
DO12: IC1.D2 (D11), IC2.6 (A5), IC3.5 (A4)
DO13: IC1.C1 (D9), IC2.7 (A6), IC3.4 (A3)
DO14: IC1.C2 (D10), IC2.8 (A7), IC3.3 (A2)
DO15: IC1.B1 (D8), IC2.9 (A8), IC3.2 (A1)
GND: C1.-, C2.-, C3.2, C4.2, C5.2, C6.2, C7.2, C8.2, C9.2, C10.2, C11.2, C12.2, C13.2, C14.2, C15.2, IC1.B5 (!CE), IC1.D1 (VSSQ), IC1.E6 (VSS), IC2.10 (GND), IC3.10 (GND), IC4.10 (GND), IC5.1 (G1), IC5.10 (GND), IC5.19 (G2), IC6.1 (G1), IC6.10 (GND), IC6.19 (G2), IC7.1 (G1), IC7.10 (GND), IC7.19 (G2), IC8.4 (VSSIO), IC8.17 (VSSINT), IC8.25 (VSSIO), IC9.2 (GND), JTAG.1, SW1.3, X1.1, X1.33, X1.34, X1.35, X1.36, X1.67, X1.68
LA1: IC1.A3 (A0), IC5.12 (Y7)
LA2: IC1.A4 (A1), IC5.14 (Y5)
LA3: IC1.A5 (A2), IC5.16 (Y3)
LA4: IC1.B3 (A3), IC5.11 (Y8)
LA5: IC1.B4 (A4), IC5.15 (Y4)
LA6: IC1.C3 (A5), IC6.17 (Y2)
LA7: IC1.C4 (A6), IC5.17 (Y2)
LA8: IC1.D4 (A7), IC7.18 (Y1)
LA9: IC1.H2 (A8), IC6.12 (Y7)
LA10: IC1.H3 (A9), IC7.11 (Y8)
LA11: IC1.H4 (A10), IC7.13 (Y6)
LA12: IC1.H5 (A11), IC7.15 (Y4)
LA13: IC1.G3 (A12), IC6.11 (Y8)
LA14: IC1.G4 (A13), IC7.14 (Y5)
LA15: IC1.F3 (A14), IC6.13 (Y6)
LA16: IC1.F4 (A15), IC7.16 (Y3)
LA17: IC1.E4 (A16), IC7.12 (Y7)
LA18: IC1.D3 (A17), IC5.13 (Y6)
LA19: IC1.H1 (A18), IC6.15 (Y4)
LA20: IC1.G2 (A19), IC6.16 (Y3)
LA21: IC1.H6 (A20), IC7.17 (Y2)
L_OE: IC1.A2 (!OE), IC6.18 (Y1)
L_WE: IC1.G5 (!WE), IC2.1 (DIR), IC3.1 (DIR), IC4.1 (DIR), IC6.14 (Y5)
unnamed: IC8.14 (PB00/14), SW1.2
OE: IC6.2 (A1), IC8.16 (PB00/15), X1.9
OE_EVEN: IC4.19 (G), IC8.27 (PB01/11)
OE_ODD: IC2.19 (G), IC8.22 (PB01/13)
OE_ODD_LOW: IC3.19 (G), IC8.23 (PB01/12)
REG#: IC8.37 (PB01/03), X1.61
TCK: IC8.11 (TCK), JTAG.3
TDI: IC8.9 (TDI), JTAG.5
TDO: IC8.24 (TDO), JTAG.2
TMS: IC8.10 (TMS), JTAG.4
WE: IC6.6 (A5), X1.15

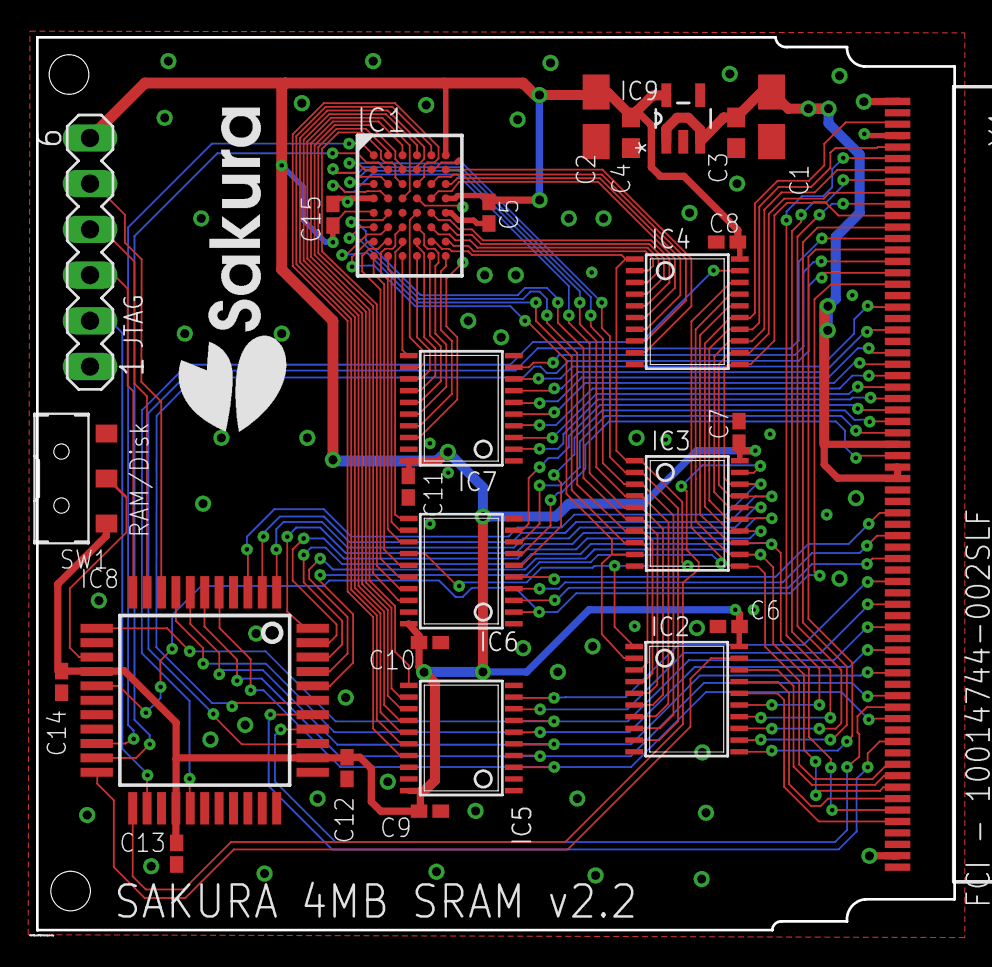
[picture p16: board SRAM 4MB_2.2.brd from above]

Board: 2 copper layers, 51.0 x 49.6 mm, 27 parts (0 on the bottom side), 95 nets.

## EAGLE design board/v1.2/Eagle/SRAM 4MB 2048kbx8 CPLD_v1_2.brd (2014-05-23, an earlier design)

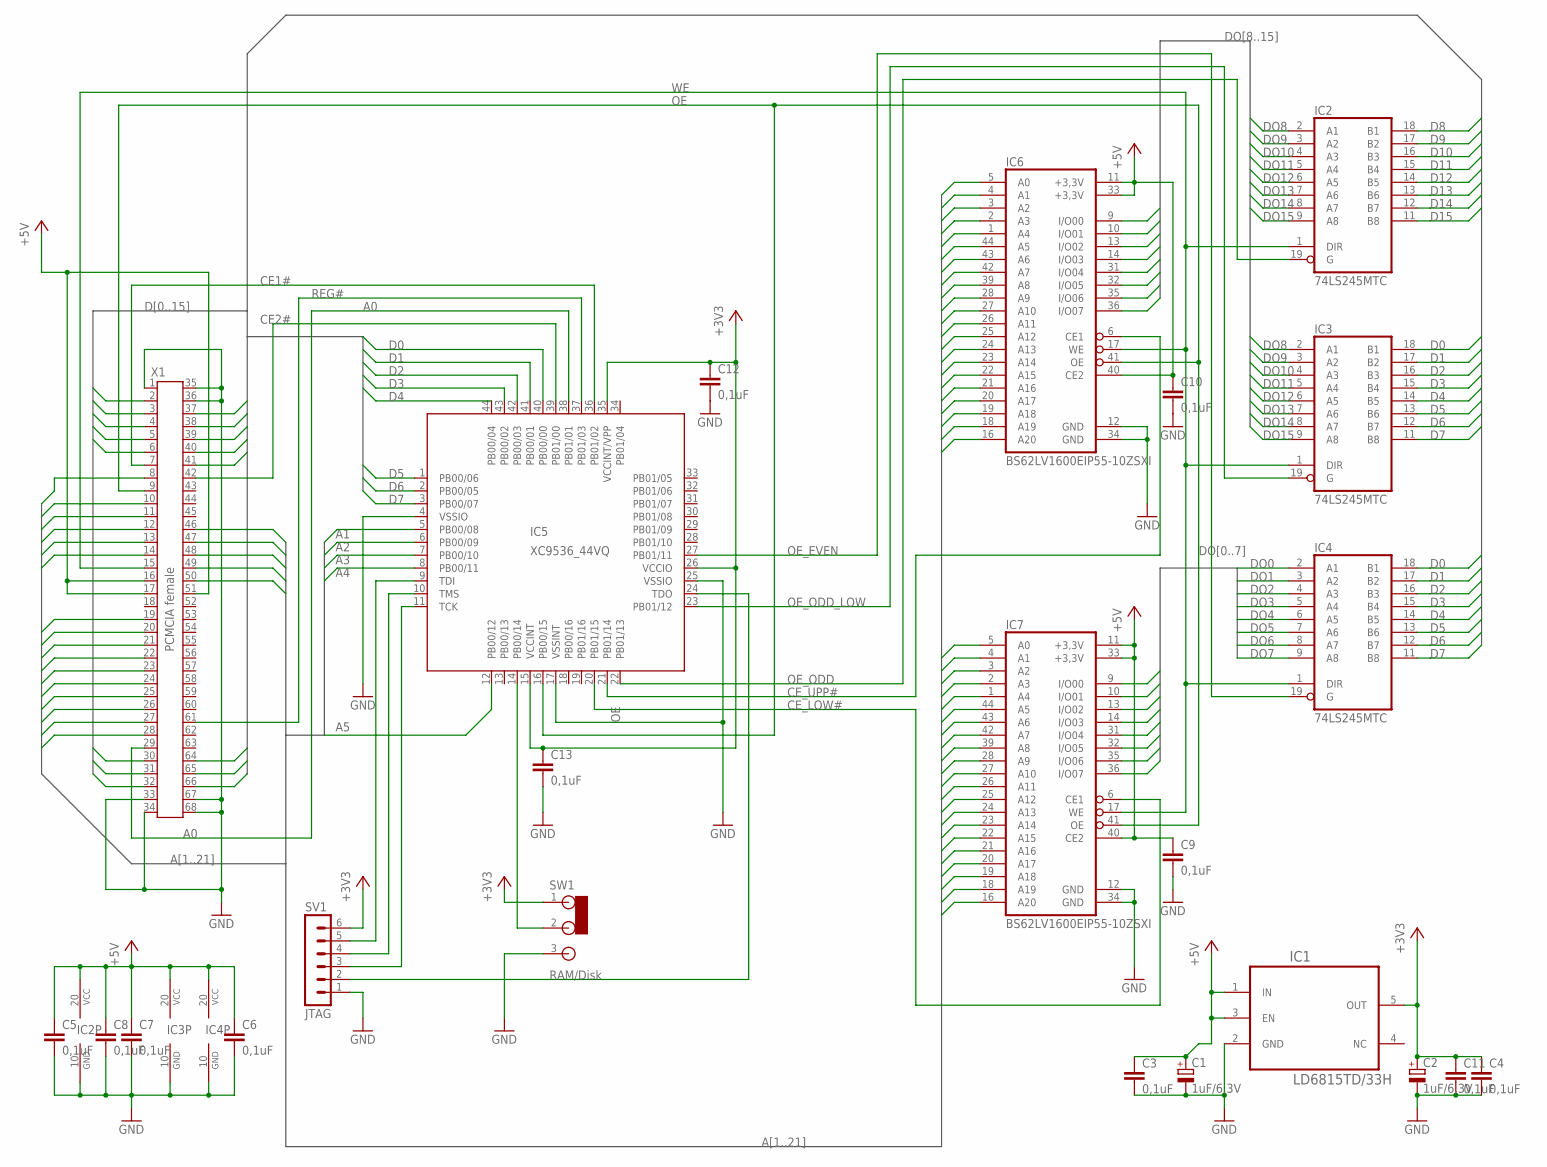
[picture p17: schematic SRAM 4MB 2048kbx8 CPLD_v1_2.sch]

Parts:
C1, C2: 1uF/6,3V; A/3216-18R
C3, C4, C5, C6, C7, C8, C9, C10, C11, C12, C13: 0,1uF; C0603
IC1: LD6815TD/33H; SOT95P275X110-5N
IC2, IC3, IC4: 74LS245MTC; TSSOP20
IC5: XC9536_44VQ; SQFP-S-10X10-44
IC6, IC7: BS62LV1600EIP55-10ZSXI; TSOPII-Z44
SV1: JTAG; MA06-1
SW1: RAM/Disk; SWITCH2
X1: PCMCIA female; 9M681X04

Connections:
+3V3: C2.+, C4.1, C11.1, C12.1, C13.1, IC1.5 (OUT), IC5.15 (VCCINT), IC5.26 (VCCIO), IC5.35 (VCCINT/VPP), SV1.6, SW1.1
+5V: C1.+, C3.1, C5.1, C6.1, C7.1, C8.1, C9.1, C10.1, IC1.1 (IN), IC1.3 (EN), IC2.20 (VCC), IC3.20 (VCC), IC4.20 (VCC), IC6.11 (+3,3V), IC6.33 (+3,3V), IC6.40 (CE2), IC7.11 (+3,3V), IC7.33 (+3,3V), IC7.40 (CE2), X1.16, X1.17, X1.51
A0: IC5.38 (PB01/01), X1.29
A1: IC5.5 (PB00/08), IC6.5 (A0), IC7.5 (A0), X1.28
A2: IC5.6 (PB00/09), IC6.4 (A1), IC7.4 (A1), X1.27
A3: IC5.7 (PB00/10), IC6.3 (A2), IC7.3 (A2), X1.26
A4: IC5.8 (PB00/11), IC6.2 (A3), IC7.2 (A3), X1.25
A5: IC5.12 (PB00/12), IC6.1 (A4), IC7.1 (A4), X1.24
A6: IC6.44 (A5), IC7.44 (A5), X1.23
A7: IC6.43 (A6), IC7.43 (A6), X1.22
A8: IC6.42 (A7), IC7.42 (A7), X1.12
A9: IC6.39 (A8), IC7.39 (A8), X1.11
A10: IC6.28 (A9), IC7.28 (A9), X1.8
A11: IC6.27 (A10), IC7.27 (A10), X1.10
A12: IC6.26 (A11), IC7.26 (A11), X1.21
A13: IC6.25 (A12), IC7.25 (A12), X1.13
A14: IC6.24 (A13), IC7.24 (A13), X1.14
A15: IC6.23 (A14), IC7.23 (A14), X1.20
A16: IC6.22 (A15), IC7.22 (A15), X1.19
A17: IC6.21 (A16), IC7.21 (A16), X1.46
A18: IC6.20 (A17), IC7.20 (A17), X1.47
A19: IC6.19 (A18), IC7.19 (A18), X1.48
A20: IC6.18 (A19), IC7.18 (A19), X1.49
A21: IC6.16 (A20), IC7.16 (A20), X1.50
CE1#: IC5.36 (PB01/02), X1.7
CE2#: IC5.39 (PB01/00), X1.42
CE_LOW#: IC5.20 (PB01/15), IC7.6 (CE1)
CE_UPP#: IC5.21 (PB01/14), IC6.6 (CE1)
D0: IC3.18 (B1), IC4.18 (B1), IC5.40 (PB00/00), X1.30
D1: IC3.17 (B2), IC4.17 (B2), IC5.41 (PB00/01), X1.31
D2: IC3.16 (B3), IC4.16 (B3), IC5.42 (PB00/03), X1.32
D3: IC3.15 (B4), IC4.15 (B4), IC5.43 (PB00/02), X1.2
D4: IC3.14 (B5), IC4.14 (B5), IC5.44 (PB00/04), X1.3
D5: IC3.13 (B6), IC4.13 (B6), IC5.1 (PB00/06), X1.4
D6: IC3.12 (B7), IC4.12 (B7), IC5.2 (PB00/05), X1.5
D7: IC3.11 (B8), IC4.11 (B8), IC5.3 (PB00/07), X1.6
D8: IC2.18 (B1), X1.64
D9: IC2.17 (B2), X1.65
D10: IC2.16 (B3), X1.66
D11: IC2.15 (B4), X1.37
D12: IC2.14 (B5), X1.38
D13: IC2.13 (B6), X1.39
D14: IC2.12 (B7), X1.40
D15: IC2.11 (B8), X1.41
DO0: IC4.2 (A1), IC7.9 (I/O00)
DO1: IC4.3 (A2), IC7.10 (I/O01)
DO2: IC4.4 (A3), IC7.13 (I/O02)
DO3: IC4.5 (A4), IC7.14 (I/O03)
DO4: IC4.6 (A5), IC7.31 (I/O04)
DO5: IC4.7 (A6), IC7.32 (I/O05)
DO6: IC4.8 (A7), IC7.35 (I/O06)
DO7: IC4.9 (A8), IC7.36 (I/O07)
DO8: IC2.2 (A1), IC3.2 (A1), IC6.9 (I/O00)
DO9: IC2.3 (A2), IC3.3 (A2), IC6.10 (I/O01)
DO10: IC2.4 (A3), IC3.4 (A3), IC6.13 (I/O02)
DO11: IC2.5 (A4), IC3.5 (A4), IC6.14 (I/O03)
DO12: IC2.6 (A5), IC3.6 (A5), IC6.31 (I/O04)
DO13: IC2.7 (A6), IC3.7 (A6), IC6.32 (I/O05)
DO14: IC2.8 (A7), IC3.8 (A7), IC6.35 (I/O06)
DO15: IC2.9 (A8), IC3.9 (A8), IC6.36 (I/O07)
GND: C1.-, C2.-, C3.2, C4.2, C5.2, C6.2, C7.2, C8.2, C9.2, C10.2, C11.2, C12.2, C13.2, IC1.2 (GND), IC2.10 (GND), IC3.10 (GND), IC4.10 (GND), IC5.4 (VSSIO), IC5.17 (VSSINT), IC5.25 (VSSIO), IC6.12 (GND), IC6.34 (GND), IC7.12 (GND), IC7.34 (GND), SV1.1, SW1.3, X1.1, X1.33, X1.34, X1.35, X1.36, X1.67, X1.68
unnamed: IC5.24 (TDO), SV1.2
unnamed: IC5.11 (TCK), SV1.3
unnamed: IC5.10 (TMS), SV1.4
unnamed: IC5.9 (TDI), SV1.5
unnamed: IC5.14 (PB00/14), SW1.2
OE: IC5.16 (PB00/15), IC6.41 (OE), IC7.41 (OE), X1.9
OE_EVEN: IC4.19 (G), IC5.27 (PB01/11)
OE_ODD: IC2.19 (G), IC5.22 (PB01/13)
OE_ODD_LOW: IC3.19 (G), IC5.23 (PB01/12)
REG#: IC5.37 (PB01/03), X1.61
WE: IC2.1 (DIR), IC3.1 (DIR), IC4.1 (DIR), IC6.17 (WE), IC7.17 (WE), X1.15

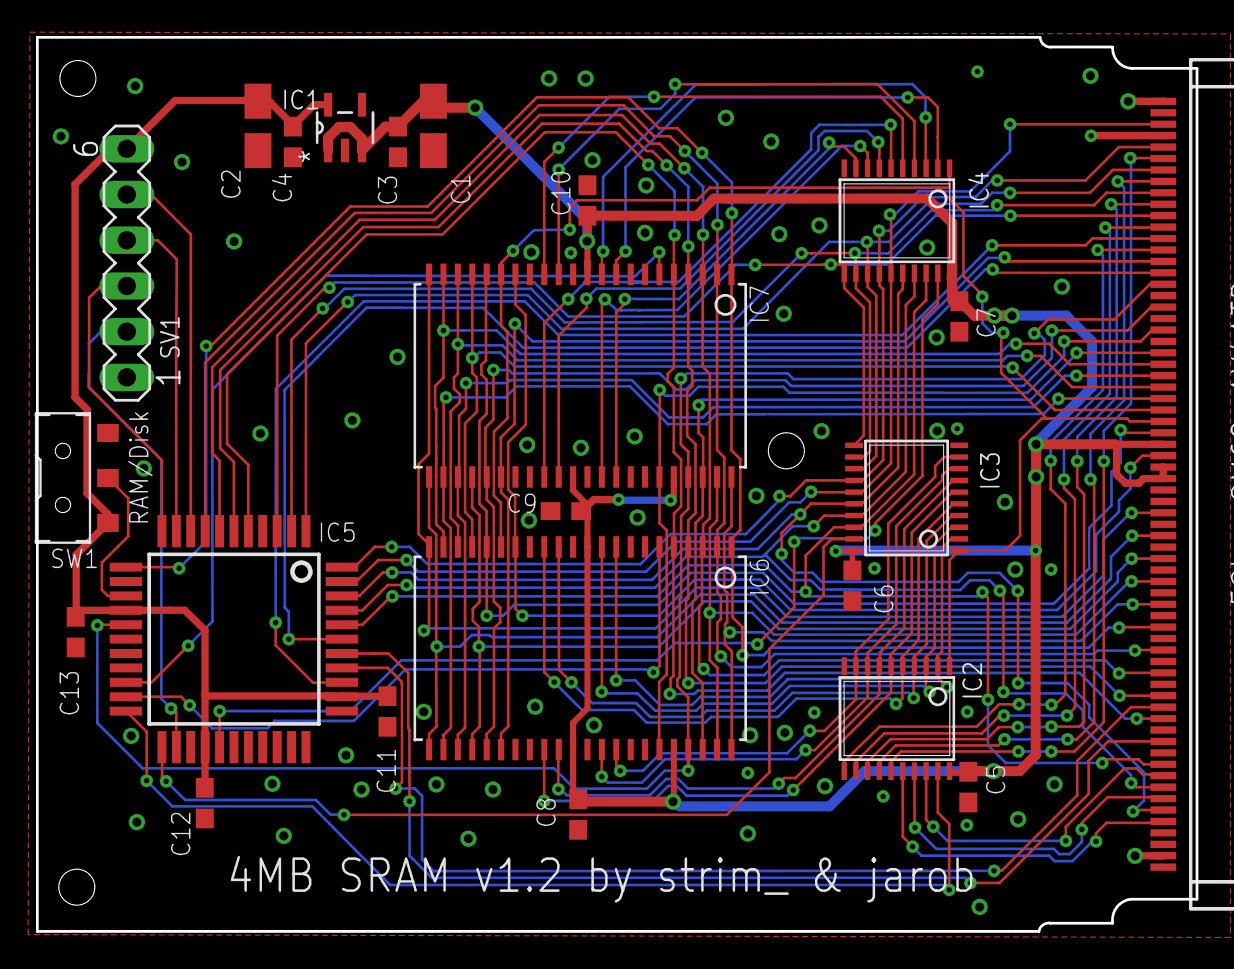
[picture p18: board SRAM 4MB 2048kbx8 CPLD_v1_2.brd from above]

Board: 2 copper layers, 64.4 x 49.7 mm, 23 parts (0 on the bottom side), 72 nets.

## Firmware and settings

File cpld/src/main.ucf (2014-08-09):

# control signals from PCMCIA
NET "ce1" LOC = "42";
NET "ce2" LOC = "1";
NET "a0" LOC = "44"; # address bus bit 0
NET "reg" LOC = "43";
NET "oe_rom" LOC = "22";  # OE from PCMCIA in fact only used by ROM

# switches/jumpers
NET "sw_rom" LOC = "20";

# control signals to memory
NET "oe_even" LOC = "33";
NET "oe_oddlow" LOC = "29";
NET "oe_odd" LOC = "28";
NET "ce_upp" LOC = "27";
NET "ce_low" LOC = "26";
NET "ce_attr_external" LOC = "25";

# address bus (in fact A1-A5)
NET "addr<0>" LOC = "11";
NET "addr<1>" LOC = "12";
NET "addr<2>" LOC = "13";
NET "addr<3>" LOC = "14";
NET "addr<4>" LOC = "18";

# lowest 8 bits of data bus
NET "data<0>" LOC = "2";
NET "data<1>" LOC = "3";
NET "data<2>" LOC = "4";
NET "data<3>" LOC = "5";
NET "data<4>" LOC = "6";
NET "data<5>" LOC = "7";
NET "data<6>" LOC = "8";
NET "data<7>" LOC = "9";

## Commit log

2014-02-14 Import latest schematics.
2014-03-06 Board in pdf, Eagle and gerber format
    [SRAM 4MB 2048kbx8 CPLD proto.brd, SRAM 4MB 2048kbx8 CPLD proto.sch]
2014-03-07 New version of board
    [SRAM 4MB 2048kbx8 CPLD proto.brd, SRAM 4MB 2048kbx8 CPLD proto.sch]
2014-03-11 Rearrange and clean up the repository contents.
    [SRAM 4MB 2048kbx8 CPLD proto.brd, SRAM 4MB 2048kbx8 CPLD proto.sch]
2014-03-13 BOM file
    [SRAM 4MB 2048kbx8 CPLD.bom.csv]
2014-05-09 New version board v1.2 on memory LY62W20488ML-55LL
    v1.2 on memory LY62W20488ML
    v2.0 on memory AS6C3216
    [SRAM 4MB 2048kbx16 CPLD_Proto.brd, SRAM 4MB 2048kbx16 CPLD_Proto.sch, SRAM 4MB 2048kbx8 CPLD proto.brd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]
2014-05-23 New version of board v2.1
    [SRAM 4MB 2048kbx16 CPLD_2.1.brd, SRAM 4MB 2048kbx16 CPLD_2.1.sch, SRAM 4MB 2048kbx8 CPLD_v1_2.brd]
2014-05-26 small change in the boards v2.1
    [SRAM 4MB 2048kbx16 CPLD_2.1.brd, SRAM 4MB 2048kbx16 CPLD_2.1.sch]
2014-06-02 Small change in the boards v2.0 and v2.1
    [SRAM 4MB 2048kbx16 CPLD_2.1.brd, SRAM 4MB 2048kbx16 CPLD_2.1.sch, SRAM 4MB 2048kbx16 CPLD_Proto.brd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]
2014-06-05 Minor updates to manual
    Rearrange stuff, add board layout image for v2.1.
2014-08-09 Complete CIS ROM in CPLD implementation.
    It is good enough for autodetection of SRAM as memory at 100ns. So far the
    RAM/disk switch just disables the CIS if set in "disk" position. Then the user
    can use PrepCard to write his own settings into beginning of common memory
    area. It needs further investigation if it makes sense to put "disk" CIS
    into CPLD (the filesystem has to be created anyway).
2014-09-11 Minor changes to english manual.
    Change paper to A4, comment out info about lack of case, as our cards
    are delivered cased.
2015-10-09 New board of PSRAM by ISSI
    [SRAM 4MB_2.2.sch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]
2015-10-10 New wersion board of PSRAM by ISSI
    [SRAM 4MB_2.2.brd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]
